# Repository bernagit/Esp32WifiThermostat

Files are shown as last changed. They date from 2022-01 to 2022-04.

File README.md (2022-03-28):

# ESP32 distribuited Thermometer

## Introduction

We made this project for an university exam, but also for improve our skill with microcontrollers, arduino and electonic in general. We started with the idea of creating a thermometer that can be viewed via telegram bot and during the implementation we decided to add some functionalities. Use of MQTT IOT protocol, photoresistor to measure brightness, use of multiple sensors, connectable from different WiFi networks, and display the information locally with a LCD.

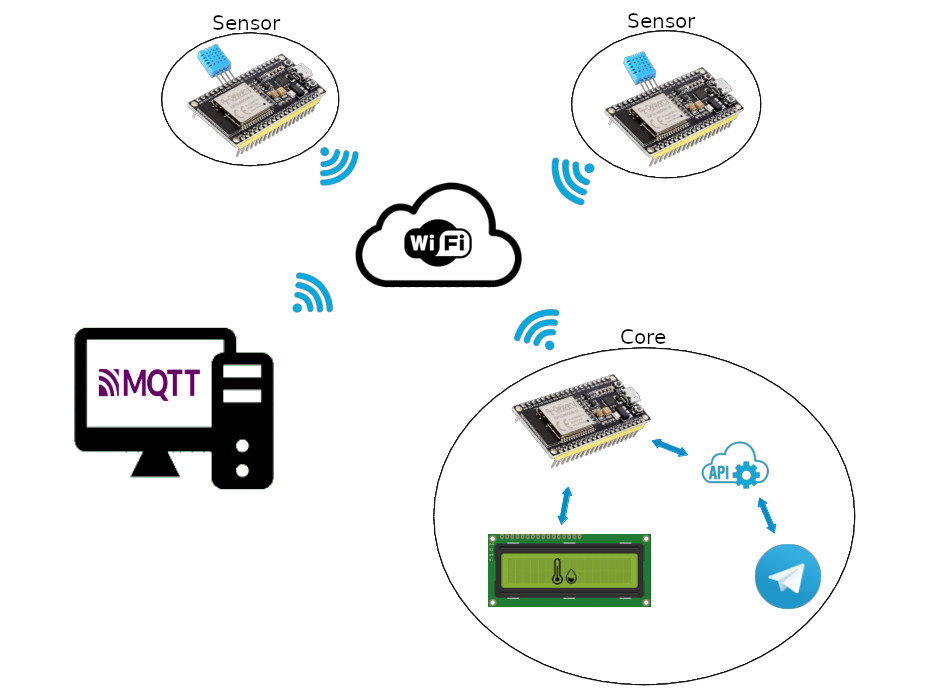
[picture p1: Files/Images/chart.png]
Project schema
- [ ] 

## How to build it

### Core of the system

##### Component List

- 1x ESP32 (with 5v output from USB)

- 1x 1602 LCD Display (not I2C version)

- 1x 10KΩ Trimmer

- 3x Button

- 3x 10KΩ Resistor

- 2x LED

##### Circuit

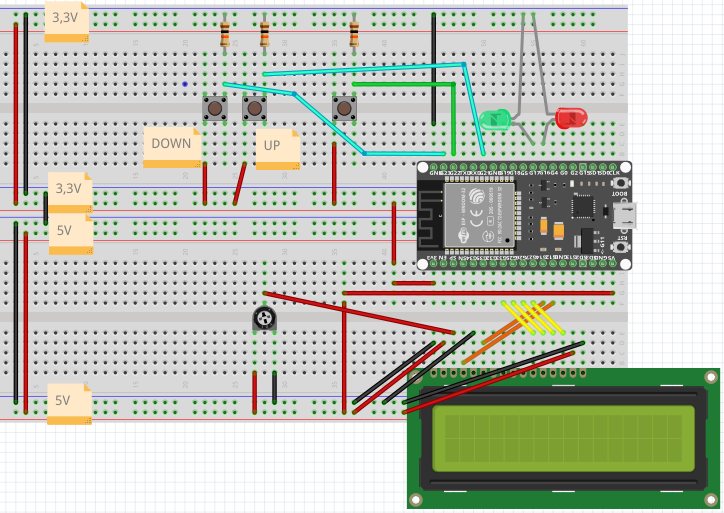
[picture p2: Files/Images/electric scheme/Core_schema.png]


### Sensor

##### Component List

- 1x ESP32 (with 5v output from USB)

- 1x 10KΩ Resistor

- 1x DHT11 Module

- 1x Photoresistor GL55

- 1x LED (or relay)

##### Photoresistor GL55

To measure enviroment brightness we decide tu use a photoresistor, a passive component that change its resistance according to the amount of light on it.

In total darkness it varies in order of MOhm, while in normal conditions it has a resistance in order of KOhm.

To connect the sensor with the microcontroller we have to make a voltage divider with a resistor of suitable value (in our case 10kOhm).

We also have to find a correct Y(gamma) value 

##### Circuit

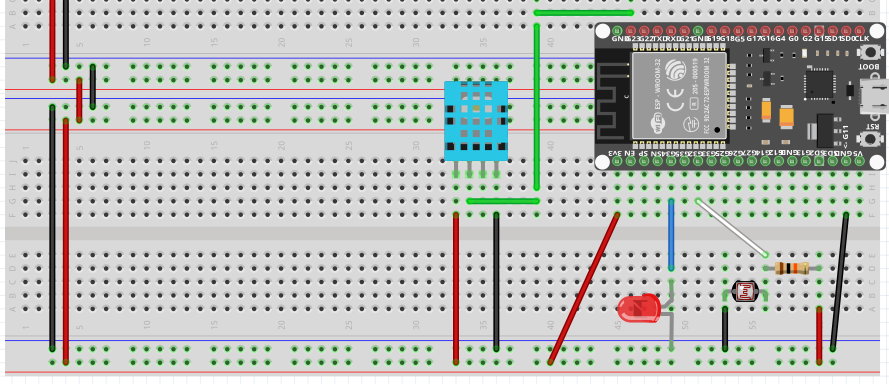
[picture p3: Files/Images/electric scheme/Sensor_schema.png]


## Communication

#### Wifi

#### MQTT

### Security Disclaimer

To make comunication between sensors and core easier we decide to use an online [MQTT Broker](https://www.mqtt-dashboard.com) that not requires credentials. Consequently the messagges from sensor are public and anyone can see them and even worse can send false data that the core will display.

In a real application sensors will publish data on a private MQTT Broker with authentication (User, Password). In this way the security of the system improves a lot.

#### Telegram

#### MultiCore

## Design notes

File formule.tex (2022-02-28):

\documentclass{article}
\usepackage[utf8]{inputenc}

\title{formule progetto elettronica}

\begin{document}
	
	\[V_0=3,3V\frac{R_p}{R_p+10K\Omega}\]	\[V_0(R_p10K\Omega)=3,3R_p\]
	\[R_p=V_0\frac{10K\Omega}{3,3V-V_0}\]
	$\log(R_p)$-$\log(10K\Omega)=\gamma^{100}_{10}[\log(lux)-\log(1)]$
	
\end{document}

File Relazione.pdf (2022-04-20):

## Progetto Arduino di Sistemi di Elettronica Digitale

## ESP32 Wifi Thermostat

Realizzato da: Bernocchi Alessandro, Ceresara Gabriele, Cherubini Mattia

Introduzione
L’obiettivo del progetto è quello di realizzare un sistema di controllo distribuito di temperatura, umidità e luminosità.
Il sistema è composto da un Core e da uno o più moduli Sensor. I Sensor sono realizzati mediante un ESP32 (sul quale è eseguito un software chiamato “Client”), un sensore di temperatura e umidità DHT11 e da un fotoresistore GL55 per la misurazione dell’intensità luminosa. Il modulo Core invece è composto da un ESP32 (sul quale è eseguito un software chiamato “Gateway”), da un display LCD non I2C e da un insieme di bottoni per la realizzazione di un’interfaccia utente locale; il Core inoltre mette a disposizione un’altro interfacciamento, realizzato mediante bot Telegram.
Il Core è in grado di rilevare nuovi sensori e aggiungerli alla lista dei sensori connessi.
Per ogni sensore collegato è possibile visualizzare temperatura, umidità e luminosità tramite telegram. Il display LCD mostra le stesse informazioni con l’aggiunta dello stato della connessione e lo stato del relè, entrambi relativi al sensore attualmente selezionato. Sono inoltre presenti 2 led di segnalazione che si attivano quando l’umidità o la temperatura rilevati da un sensore superano una certa soglia.
Dal core è possibile settare per ogni sensore la temperatura di attivazione del relè.
Le diverse entità del sistema comunicano tramite la stessa Wireless LAN oppure attraverso una diversa rete Wireless, appoggiandosi sul protocollo MQTT.

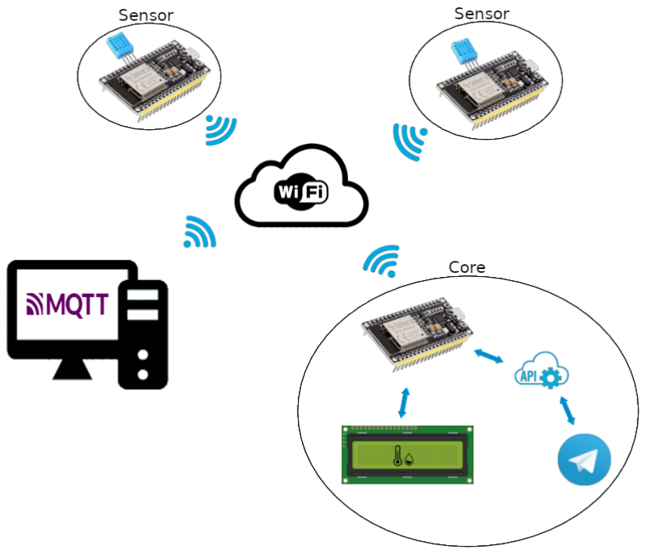
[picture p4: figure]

Comunicazione
La comunicazione avviene tra il Core e i vari Sensor in modo bidirezionale (entrambi i moduli inviano e ricevono informazioni).

I vari Sensor inviano al Core ogni 7 secondi i valori di temperatura, umidità e luminosità rilevati tramite i loro sensori.
Il Core invia ai vari Sensor i valori di temperatura impostati dall’utente tramite l’interfaccia locale, utili ad accendere o spegnere il relè usato per simulare un sistema di riscaldamento. Tale dato viene mandato ad un Sensor specifico (non viene ricevuto quindi da tutti, ma solo dal Sensor selezionato dall’utente).

How to build it

Core (sistema di controllo dei sensori)

Lista componenti
- 1x ESP32
- 1x Display 16x02 (non I2C)
- 1x Potenziometro 10kΩ
- 3x Bottone NA
- 3x Resistenza 10kΩ
- 2x Led

Realizzazione circuitale

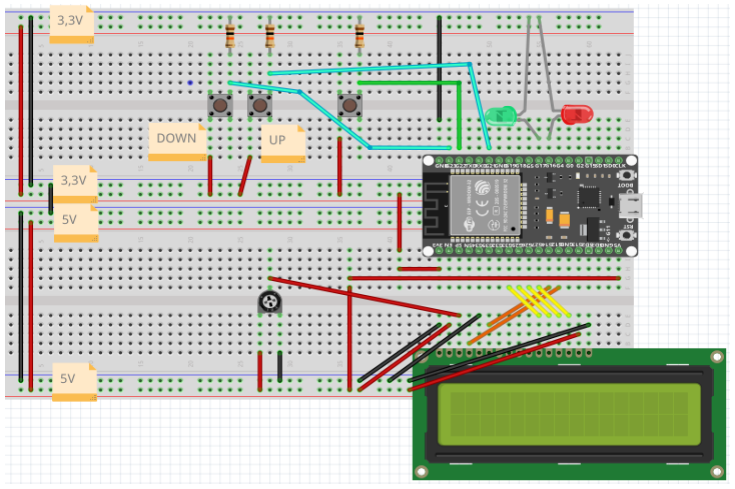
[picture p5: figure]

Sensore

Lista componenti
- 1x ESP32
- 1x Resistenza 10kΩ
- 1x Modulo DHT11
- 1x Fotoresistore GL55
- 1x Led

Fotoresistore GL55
Per la misurazione della luminosità ambientale si utilizza un fotoresistore, componente passivo che fa variare la sua resistenza inversamente alla quantità di luce presente.

In particolare, in condizioni di buio totale varia nell’ordine dei MOhm, mentre in un ambiente illuminato è nell’ordine dei KOhm .
Il sensore non può essere direttamente collegato all’ingresso del microcontrollore poiché esso è in grado di elaborare solamente dati in tensione. Va quindi inserito in un partitore di tensione con un resistore dal valore adeguato. (Nel nostro caso 10kΩ)
Non sapendo quale sensore della serie GL55 fosse a nostra disposizione è stato necessario stimare il valore di γ in modo da ricavare un coefficiente opportuno da utilizzare poi per la conversione del segnale in ingresso in Lux.
La lettura avviene tramite la funzione Arduino analogRead() la quale legge il valore del pin tramite l’attivazione di un ADC a 12 bit integrato nel microcontrollore in grado di restituirci
un valore nel range [0-4095].
Tramite il partitore di tensione si ricava la relazione che descrive la resistenza del componente che potrà essere convertita in Lux tramite le seguenti formule.

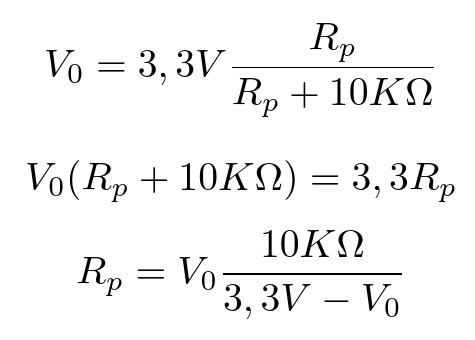
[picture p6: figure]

Realizzazione circuitale

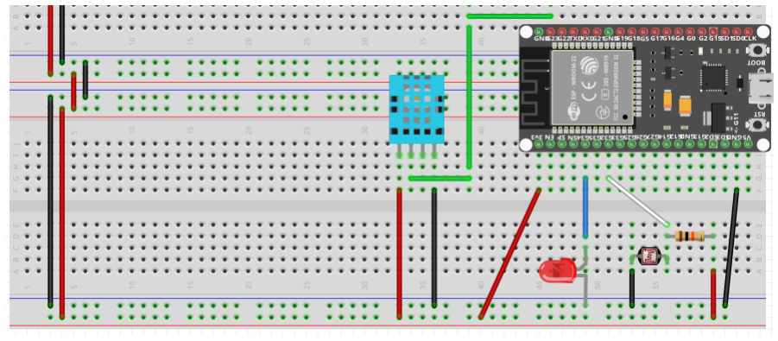
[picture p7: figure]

Communication Protocols

WIFI
La connessione al wifi è gestita tramite la libreria <Wifi.h>.
E’ necessario però definire la modalità di utilizzo tramite il metodo WiFi.mode(WIFI_STA) poiché il microcontrollore può agire anche come Access Point.

MQTT
Il protocollo di comunicazione usato dai dispositivi appartenenti al sistema è MQTT, un protocollo di rete basato sul pattern publish-subscribe, dove lo scambio di informazioni avviene tramite messaggi. Tale protocollo è ampiamente utilizzato in tutti gli ambiti nei quali esistono dei vincoli relativi alle risorse utilizzabili e dove la larghezza di banda è limitata.
MQTT definisce principalmente 2 entità: un message broker e dei client. Il broker è il server che riceve tutti i messaggi dai client e si occupa dell’inoltro delle informazioni alle destinazioni corrette, mentre i client sono un numero arbitrario di dispositivi che si collegano al broker (tramite la rete) per comunicare con il resto del sistema. Lo scambio di messaggi tra i vari client connessi al broker avviene tramite 2 azioni principali: publish e subscribe. Con l’esecuzione di una publish, un dispositivo manda informazioni; in questo caso è necessario specificare il topic sul quale eseguire l’azione e il messaggio da inviare. Sarà poi il broker ad inoltrare il messaggio a tutti i client che preventivamente avevano effettuato una subscribe nei confronti di quello specifico topic.
Nel nostro sistema l’uso del protocollo MQTT avviene tramite la libreria <PubSubClient.h>, la quale fornisce delle strutture dati e funzioni che permettono un’implementazione semplificata di tale protocollo. I metodi usati sono i seguenti:
PubSubClient client(WifiClient wifiClient) | Costruttore del client mqtt, al quale è necessario fornire il client wifi.
setServer(char* host. int port) | Imposta le informazioni relative al broker MQTT al quale ci si vuole collegare.
connect(char* name) | Si collega al broker MQTT specificato (necessario chiamare prima il metodo indicato sopra).
subscribe(char* topic) | Azione di subscribe al topic specificato come parametro
unsubscribe(char* topic) | Annulla l’azione di subscribe al topic specificato come parametro
publish(char* topic, char* msg) | Azione di publish del messaggio sul topic specificato
setCallback(function* callback) | Imposta la funzione di callback del client. Essa è chiamata ogni volta che arriva un messaggio su uno dei topic ai quali il client ha eseguito l’azione di subscribe. La funzione di callback ha come parametri un char* dove viene specificato il topic dal quale proviene il messaggio, e un char*, il quale rappresenta il messaggio vero e proprio

Nel sistema i client effettuano delle publish su topic che presentano un pattern simile: {device_id}/{data}, ovvero nella prima parte indicano il loro id (per distinguersi dagli altri dispositivi) mentre nella seconda il tipo di dato che è presente nel messaggio (nel nostro caso vengono inviate temperatura, umidità e luminosità).

Breve nota sulla sicurezza
Per semplificare la visione del progetto funzionante in università abbiamo utilizzato un MQTT Broker online (www.mqtt-dashboard.com) che non richiede credenziali. Di conseguenza:
- I messaggi inviati dai sensori sono non cifrati e visibili a tutti
- Non c’è autenticazione tra sensori e sistema centrale pertanto chiunque scriva sullo stesso Topic MQTT può introdurre dati errati che poi verranno visualizzati senza nessun controllo.
In un’applicazione reale del progetto i sensori pubblicano i loro messaggi cifrati su un Broker MQTT Privato tramite autenticazione (user e password). In questo modo si risolvono entrambi i problemi citati prima.

Telegram
La comunicazione con Telegram è gestita tramite un BOT. L’utente può inviare i comandi nella chat del BOT. Se l’utente è autorizzato gli verrà inviato un messaggio contenente una visione dei dati inviati al Core da parte dei Client MQTT al momento connessi, in caso contrario riceverà un messaggio di errore.

Lista dei comandi validi:

/start | Utente autorizzato avvia la comunicazione
/sensors | Visualizza la lista di sensori al momento connessi
/RoomN | Visualizza i dati di uno degli N sensori connessi

L’interazione è resa possibile dalle librerie <UniversalTelegramBot.h> e <ArduinoJSON.h> tramite il seguente procedimento. Quando una richiesta da parte di un utente autorizzato ha successo le informazioni relative al bot, alla chat ed allo stesso utente vengono salvate in un oggetto con il formato JSON. La comunicazione è gestita tramite un’apposita libreria che ci fornisce i seguenti metodi:

UniversalTelegramBot bot (BOTtoken, BOTclient) | Costruttore del bot con il suo token ed il client Wi-Fi
getUpdates (int msg) | Restituisce l’aggiornamento di quanti messaggi sono stati recentemente ricevuti
sendMessage (chat_id, message) | Invia un messaggio “message” sulla chat “chat_id”
bot.messages[int i] | Posizione specifica del messaggio scambiato nell’ array che li contiene
chat_id | Identificazione dell’utente
text | Contenuto testuale del comando
from_name | Contiene l’username dell’utente che invia la richiesta

MultiCore
Gli ESP-32 impiegati nel sistema sono tutti dotati di un processore dual-core, grazie al quale possono essere eseguiti più processi contemporaneamente per migliorare le prestazioni di ogni dispositivo. Questa funzionalità è utilizzabile grazie alla presenza di un sistema operativo real time (FreeRTOS) tramite il quale, con opportune API, è possibile creare dei task specificando il core sul quale devono essere eseguiti. La presenza di un RTOS permette anche di assegnare delle priorità ai vari task, che verranno gestite da quest’ultimo. La funzione usata per la generazione e l’esecuzione dei vari task è xTaskCreatePinnedToCore (documentazione delle API messe a disposizione da FreeRTOS qui). (https://docs.espressif.com/projects/esp-idf/en/latest/esp32/api-reference/system/freertos.html)
Nel nostro caso, il dual core è stato sfruttato dal sistema di controllo per gestire principalmente i task relativi alla scrittura su display LCD e alla gestione del bot Telegram, i 2 computazionalmente più “pesanti”. Ad essi è stato assegnato un core separato ed una priorità maggiore, per fare in modo che l’interazione con l’utente sia il più veloce possibile (a discapito di altri task reputati
meno importanti, come ad esempio la gestione degli interrupt generati dall’arrivo di un messaggio MQTT).

Power Save
Il sistema di controllo utilizza 2 core e sfrutta al massimo le potenzialità del processore, inoltre ha un display sempre attivo, per questo si presuppone che sia alimentato tramite apposito alimentatore.

Per quanto riguarda i sensori, si cerca invece di ridurre i consumi per un possibile utilizzo a batteria.
Si utilizza quindi la funzione esp_wifi_set_ps(WIFI_PS_MIN_MODEM) la quale rallenta la frequenza di arrivo dei messaggi Beacon con la stessa frequenza del periodo DTIM.
E’ necessario inoltre diminuire la frequenza del clock del microcontrollore con la funzione setCpuFrequencyMhz(int frequency). Nel nostro caso la frequenza del clock viene abbassata da 240MHz a 80MHz.
Risultati ottenuti:

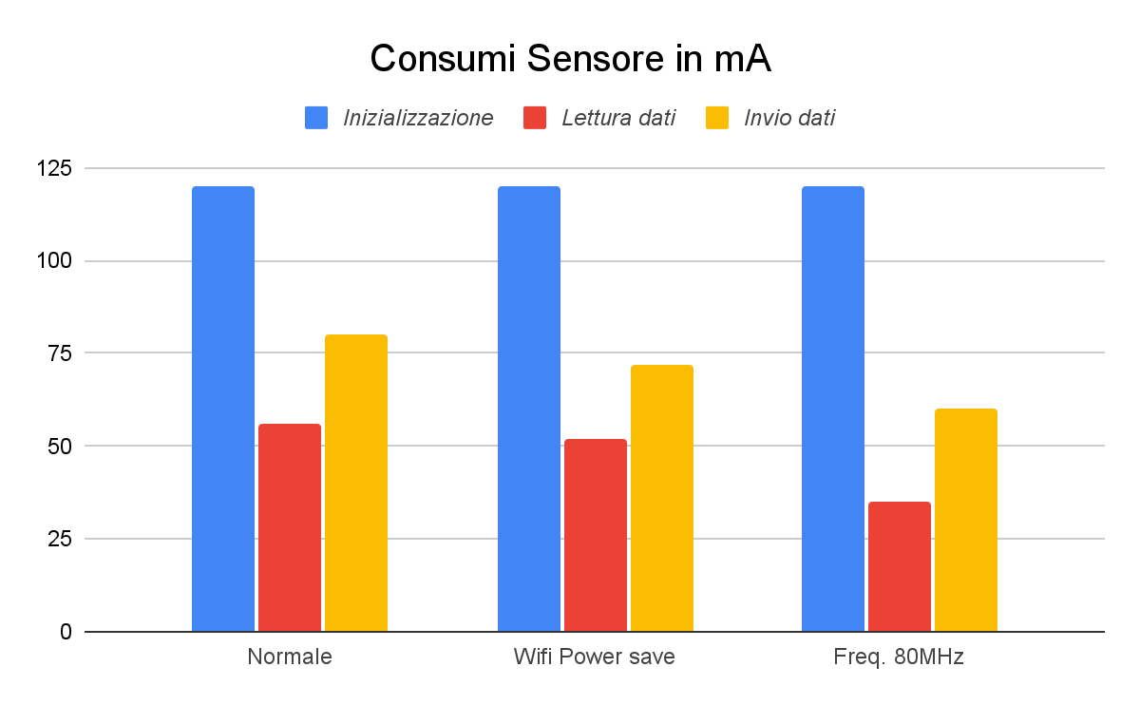
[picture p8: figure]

(documentazione API di ESPRESSIF qui) (https://docs.espressif.com/projects/esp-idf/en/latest/esp32/api-reference/index.html)

Display LCD
Per la visualizzazione “in locale” dei dati è stato usato un display 16x2 non I2C che dispone di 16 colonne e 2 righe. Indicata qui sotto una tabella con i diversi pin ed uno schema:

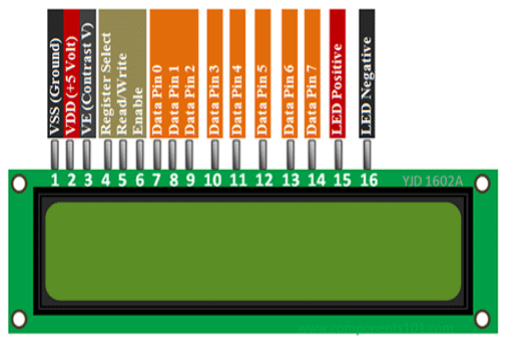
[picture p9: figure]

La programmazione avviene tramite la libreria <LiquidCrystal.h> della quale abbiamo utilizzato i seguenti metodi:

LiquidCrystal lcd(rs, enable, d4, d5, d6, d7) | Permette di creare l’oggetto inizializzando i pin connessi
lcd.begin(col, row) | Inizializzo la righe e le colonne scrivibili
lcd.setCursor(col, row) | Setto il cursore in un punto del display

lcd.print(data) | Scrive la stringa “data” dalla posizione del cursore
lcd.createChar(num, Byte data[8]) | Crea un char personalizzato assegnando un numero [0-7]
lcd.write(data) | Scrive il carattere “data” dalla posizione del cursore

Il sistema può trovarsi in uno di due stati:
- WAITING: In attesa che qualcuno si colleghi mostra l’interfaccia base, con gli slot dei dati vuoti.
- DISPLAYING: Con uno o più Sensori connessi mostra i dati ricevuti da uno di essi. Poiché il sistema è scalabile fino ad un massimo di 10 Sensori ed è possibile visualizzare sullo schermo le informazioni relative ad un solo client per volta il cambio di visualizzazione della “stanza” è gestito tramite un bottone.

Sistema di Allarmi
Il sistema di allarmi è composto da due LED sulla stazione centrale:
- LED Rosso: si accende se la Temperatura supera la soglia definita
- LED Verde: si accende se l’Umidità supera la soglia definita
Il led viene settato con la funzione digitalWrite(pin, HIGH/LOW) la quale dà un uscita digitale sul pin settato come uscita con la funzione pinMode(pin, OUTPUT), attivando il buffer Three-State posto sul GPIO selezionato.

Regolazione temperatura
Ogni sensore ha un led il quale si attiva quando la temperatura letta è inferiore ad una soglia. Tale soglia è definibile soltanto dal Core tramite appositi bottoni. Una volta settata, verrà inviata tramite MQTT al sensore.
Per semplicità il led rappresenta un relè. l’attivazione e la disattivazione corrispondono al funzionamento di un termostato.

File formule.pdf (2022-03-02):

V0 = 3, 3V

Rp
Rp + 10KΩ

V0(Rp + 10KΩ) = 3, 3Rp

Rp = V0

10KΩ
3, 3V − V0

log(Rp)-log(100KΩ) = −γ

100
10 [log(lux) − log(1)]

Luce[lux] = 10[( ⁻¹
γ

) log( Rp
100K )]

1

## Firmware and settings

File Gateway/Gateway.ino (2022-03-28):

#include <ArduinoJson.h>
#include <UniversalTelegramBot.h>
#include <WiFi.h>
#include <WiFiClient.h>
#include <WiFiClientSecure.h>
#include <LiquidCrystal.h>
#include <PubSubClient.h>
#include "Gateway.h"

/**
 * Struttura nella quale vengono salvati i dati relativi ad ogni
 * sensore connesso al sistema
 */
struct Sensor {
  String name;
  int lastConnection;
  String temperature;
  String humidity;
  String brightness;
  float setTemp;
};
//Lista dove vengono salvati tutti i sensori connessi
Sensor sensors[MAX_SENSOR_NUM];
/**
 * Indice che "scorre" sulla lista definita sopra. Questo indice punta
 * al sensore del quale si vogliono scrivere le informazioni sullo schermo
 * LCD. Ogni volta che il bottone viene premuto il suo valore è incrementato,
 * e nel caso superi il limite (arraySize, definito sotto) allora riparte da 0
 */
int selectedIndex = -1;
/**
 * Variabile che salva il numero di sensori attualmente attivi
 * Viene incrementata ogni volta che un nuovo sensore si connette
 */
int arraySize = 0;

//inizializzazione del display
LiquidCrystal lcd(14, 12, 33, 25, 26, 27);

//inizializzazione oggetti per Telegram
WiFiClientSecure clientSec;
UniversalTelegramBot bot(BOTtoken, clientSec);

unsigned long lastTimeBotRan;

//inizializzazione oggetti per MQTT
WiFiClient espClient;
PubSubClient client(espClient);

//funzione per la connessione al WIFI
void connectToWifi() {
  Serial.println("");
  Serial.print("Connecting to ");
  Serial.print(WIFI_SSID);

  WiFi.mode(WIFI_STA);
  WiFi.begin(WIFI_SSID, WIFI_PASSWORD);

  #ifdef ESP32
    clientSec.setCACert(TELEGRAM_CERTIFICATE_ROOT); // set del certificato root per api.telegram.org
  #endif
  
  while (WiFi.status() != WL_CONNECTED) {
    delay(DELAY_WIFI_TRY);
    Serial.print(".");  
  }

  Serial.println("");
  Serial.println("Wifi connected");
  Serial.println("Indirizzo IP: ");
  Serial.println(WiFi.localIP());
}
//interrupt per i tasti regolazione temperatura
int timeUpDown = 0;
bool upPressed = false;
bool downPressed = false;

void IRAM_ATTR butUpInterrupt(){
  upPressed = true;
}
void IRAM_ATTR butDownInterrupt(){
  downPressed = true;
}

//interrupt per il tasto che cambia schermata
bool buttonPressed = false;
void IRAM_ATTR buttonPressedInterrupt() {
  if(timeUpDown == 0) {
    buttonPressed = true; 
  }
}

void setTemperature(String sensorName, float temperature) {
  String topic = "progettoEle/" + sensorName + "/setT";
  client.publish(topic.c_str(), String(temperature).c_str());
}

int clearSensorList() {
  Sensor newArray[MAX_SENSOR_NUM];
  int newSize = 0;
  int now = millis();
  
  for(int i = 0; i < arraySize; i++) {
    if(now - sensors[i].lastConnection < DELETE_SENSOR_TIME * 1000) {
      newArray[newSize] = sensors[i];
      newSize++;

      //Ai sensori collegati invia la temperatura settata
      String topic = "progettoEle/" + sensors[i].name + "/setT";
      client.publish(topic.c_str(), String(sensors[i].setTemp).c_str());
    }
  }

  if(newSize == 0) {
    selectedIndex = -1;
  } else {
    selectedIndex = 0;
  }

  int difference = arraySize - newSize;
  arraySize = newSize;

  for(int i = 0; i < newSize; i++) {
    sensors[i] = newArray[i];
  }

  return difference;
}

int startMillisDrawTask = 0;
int startMillisClearSensorsList = millis();
/**
 * Funzione che gestisce la scrittura sul display LCD
 */
void DrawTaskCode(void* param) {
  for(;;) {
    delay(DELAY_WATCHDOG_RESET);
    int currentMillis = millis();
  
    if(currentMillis - startMillisDrawTask >= REFRESH_RATE){
      if(buttonPressed && selectedIndex != -1) {
        buttonPressed = false;
        selectedIndex = (selectedIndex + 1) % arraySize;
      }
    
      startMillisDrawTask = currentMillis;
      draw();
    }

    if(currentMillis - startMillisClearSensorsList >= CLEAR_SENSOR_LIST_RATE * 1000) {
      client.unsubscribe("progettoEle/#");
      
      int deleted = clearSensorList();
      if(deleted > 0) {
        lcd.clear();
        lcd.home();
        lcd.print("Deleted ");
        lcd.print(deleted);
        lcd.setCursor(0, 1);
        lcd.print("sensors");
        digitalWrite(HUMIDITY_ALARM_PIN, LOW);
        digitalWrite(TEMPERATURE_ALARM_PIN, LOW);
        delay(DELAY_AFTER_REMOVED_SENSOR);
      }

      client.subscribe("progettoEle/#");
      startMillisClearSensorsList = currentMillis;
    }
  }
}
TaskHandle_t DrawTask;

void callback(char* topic, byte* message, unsigned int length) {
  Serial.print("Message arrived on topic: ");
  Serial.print(topic);
  Serial.print(". Message: ");
  String messageTemp;
  
  for (int i = 0; i < length; i++) {
    Serial.print((char)message[i]);
    messageTemp += (char)message[i];
  }

  int firstIndex = String(topic).indexOf('/');
  String rightTopic = String(topic).substring(firstIndex + 1);
  int secondIndex = rightTopic.indexOf('/');
  String espId = rightTopic.substring(0, secondIndex);
  String param = String(rightTopic).substring(secondIndex + 1);

  Sensor s = {"", 0, "----", "--", "--", 15.0};
  Sensor *sensor = &s;
  for(int i = 0; i < arraySize; i++) {
    if(sensors[i].name == espId) {
      sensor = &sensors[i];
    }
  }

  if(sensor->name == "" && arraySize < MAX_SENSOR_NUM) {
    sensor->name = espId;
    sensors[arraySize] = *sensor;
    arraySize++;

    if(arraySize == 1) {
       selectedIndex = 0;
    }

    setTemperature(espId, 15.0);
  }

  sensor->lastConnection = millis();
  if(param == "temperature") {
    //tronco il valore di temperatura a 3 caratteri per la visualizzazione su display
    messageTemp.remove(4);
    sensor->temperature = messageTemp;
  }
  if(param == "humidity") {
    sensor->humidity = messageTemp;
  }
  if(param == "brightness") {
    sensor->brightness = messageTemp;
  }
}

void draw() {
  lcd.setCursor(0, 0);
  if(selectedIndex == -1) {
    lcd.print("Waiting for     ");
    lcd.setCursor(0, 1);
    lcd.print("connections     ");
    return;  
  }
  Serial.println(selectedIndex);
  Sensor sensor = sensors[selectedIndex];
  if(sensor.temperature.toFloat() >= WARNING_TEMP) {
    digitalWrite(TEMPERATURE_ALARM_PIN, HIGH);
  } else {
    digitalWrite(TEMPERATURE_ALARM_PIN, LOW);
  }

  if(sensor.humidity.toFloat() >= WARNING_HUM) {
    digitalWrite(HUMIDITY_ALARM_PIN, HIGH);
  } else {
    digitalWrite(HUMIDITY_ALARM_PIN, LOW);
  }
  
  lcd.print(sensor.name);
  lcd.print(" ");
  lcd.write(1);
  lcd.print(" " + sensor.temperature);
  lcd.print((char)223);
  lcd.print("C");

  lcd.setCursor(0, 1);
  lcd.write(2);
  lcd.print(" " + sensor.humidity + "%  ");

  lcd.setCursor(6, 1);
  lcd.write(3);
  lcd.print(" " + sensor.brightness + " lux ");

  
  lcd.setCursor(15, 0);
  if(sensor.temperature.toFloat() < sensor.setTemp ){
    lcd.write(5);
  }
  /**
   * Se il sensore non si connette da più di 30 secondi, viene segnalato tramite
   * un'icona nell'angolo in alto a destra del display
   * Nel ramo else viene scritto uno spazio bianco per "pulire" nel caso l'icona
   * vada eliminata
   */
  else if(millis() - sensor.lastConnection > DELAY_SENSOR_WARNING * 1000) {
    lcd.write(4);
  } else {
    lcd.print(" ");
  }
}
//funzione per la connessione al server MQTT
void connectToMQTTServer() {
  //Cicla fino a che non si connette
  while (!client.connected()) {
    Serial.print("Attempting MQTT connection...");
    //Prova a connettersi
    if (client.connect("ESP_GATEWAY")) {
      Serial.println("connected");
      //Se la connessiona va a buon fine, si fa la subscribe al topic
      client.subscribe("progettoEle/#");
    } else {
      //Se la connessione non va a buon fine, si scrivono le informazioni di errore e si riprova dopo 1 secondo
      Serial.print("failed, rc=");
      Serial.print(client.state());
      Serial.println(" try again in 5 seconds");

      delay(DELAY_AFTER_SETUP);
    }
  }
}

/**
 * Funzione che gestisce il bot telegram
 */
void TelegramBotTaskCode(void* param) {
  for(;;) {
    delay(DELAY_WATCHDOG_RESET);
    if (millis() > lastTimeBotRan + BOT_DELAY_REFRESH)  {
      int numNewMessages = bot.getUpdates(bot.last_message_received + 1);
      while(numNewMessages) {
        Serial.println("got response");
        handleNewMessages(numNewMessages);
        numNewMessages = bot.getUpdates(bot.last_message_received + 1);
      }
      lastTimeBotRan = millis();
    }
  }
}
TaskHandle_t TelegramBotTask;
//funzione che si occupa della ricezione dei messaggi e della risposta
void handleNewMessages(int numNewMessages) {
  Serial.println("handleNewMessages");
  Serial.println(String(numNewMessages));

  for (int i=0; i<numNewMessages; i++) {
    // Chat id of the requester
    String chat_id = String(bot.messages[i].chat_id);
    if(String(CHATS_ID).indexOf(chat_id) == -1){
      bot.sendMessage(chat_id, "Unauthorized user " + chat_id, "");
      continue;
    }
    
    // Print the received message
    String text = bot.messages[i].text;
    Serial.println(text);

    String from_name = bot.messages[i].from_name;

    if (text == "/start") {
      String welcome = "Welcome, " + from_name + ".\n";
      welcome += "Use the following command to know the connected sensor.\n\n";
      welcome += "/sensors\n";
      bot.sendMessage(chat_id, welcome, "");

      continue;
    }

    if(text == "/sensors") {
      if(arraySize == 0) {
        bot.sendMessage(chat_id, "No sensor is connected. Try later", "");
        continue;
      }

      String devicesList = "Sensors connected:\n";
      for(int i = 0; i < arraySize; i++) {
        devicesList += "/" + sensors[i].name + "\n";
      }

      bot.sendMessage(chat_id, devicesList, "");
      continue;
    }

    String sensorName = text.substring(1);
    Sensor sensor = {"", 0, "", "", ""};
    for(int i = 0; i < arraySize; i++) {
        if(sensors[i].name == sensorName) {
          sensor = sensors[i];
          break;
        }
    }

    String sensorInfo;
    if(sensor.name == "") {
      sensorInfo = "Sensor with name " + sensorName + " not found";
    } else {
      sensorInfo = "Data of " + sensorName + "\n";
      sensorInfo += "Temperature: " + sensor.temperature + "°C\n";
      sensorInfo += "Humidity: " + sensor.humidity + "%\n";
      sensorInfo += "Brightness: " + sensor.brightness + "lux\n";
    }

    bot.sendMessage(chat_id, sensorInfo, "");
  }
}

void setup() {
  Serial.begin(115200);

  //Pin degli allarmi settati come output
  pinMode(TEMPERATURE_ALARM_PIN, OUTPUT);
  pinMode(HUMIDITY_ALARM_PIN, OUTPUT);

  //Per sicurezza li setto subito a low, se dovranno essere high verrano impostati nella funzione draw
  digitalWrite(TEMPERATURE_ALARM_PIN, LOW);
  digitalWrite(HUMIDITY_ALARM_PIN, LOW);
  
  //pin del bottone come input
  pinMode(BUTTON_PIN, INPUT_PULLUP);
  attachInterrupt(BUTTON_PIN, buttonPressedInterrupt, FALLING);

  //setup pin regolazione temperatura
  pinMode(PINUP, INPUT_PULLUP);
  pinMode(PINDOWN, INPUT_PULLUP);
  attachInterrupt(PINUP, butUpInterrupt, FALLING);
  attachInterrupt(PINDOWN, butDownInterrupt, FALLING);
  
  // Setto il numero di righe e di colonne del display
  lcd.begin(16, 2);
  //Messaggio iniziale
  lcd.print("Welcome...");
  lcd.setCursor(0, 1);
  lcd.print("WIFI Thermostat");
  //creo i caratteri speciali per LCD
  lcd.createChar(1, termometro);
  lcd.createChar(2, goccia);
  lcd.createChar(3, lampadina);
  lcd.createChar(4, warning);
  lcd.createChar(5, fuego);
  //Connessione al wifi
  connectToWifi();
  delay(DELAY_AFTER_SETUP);

  //connessione a MQTT
  client.setServer(MQTT_HOST, MQTT_PORT);
  client.setCallback(callback);

  draw();

  //Istanziamento del task relativo alla gestione della scrittura sul display sul primo core del processore
  xTaskCreatePinnedToCore(DrawTaskCode, "DrawTask", 10000, NULL, 1, &DrawTask, 0);
  //Istanziamento del task relativo alla gestione del bot telegram sul secondo core del processore
  xTaskCreatePinnedToCore(TelegramBotTaskCode, "TelegramBotTask", 10000, NULL, 1, &TelegramBotTask, 1);
}

void loop() {
  if (!client.connected()) {
    connectToMQTTServer();
  }
  client.loop();
  //invio il messaggio sulla temperatura settata localmente
  if(timeUpDown != 0 && millis() - timeUpDown >= TIMEVISIBLE){
    setTemperature(sensors[selectedIndex].name, sensors[selectedIndex].setTemp);
    timeUpDown = 0;
    vTaskResume(DrawTask);
  }
  //gestione temperatura del riscaldamento tramite i 2 tasti
  if(upPressed){
    if(selectedIndex == -1)
      return;
    timeUpDown = millis();
    if(eTaskGetState(DrawTask) != eSuspended){
      vTaskSuspend(DrawTask);
    }
    sensors[selectedIndex].setTemp += 0.5;
    lcd.clear();
    lcd.print("Imposto temp a:");
    lcd.setCursor(1, 1);
    lcd.print(sensors[selectedIndex].setTemp);
    lcd.print((char)223);
    lcd.print("C");
    upPressed = false;
  }
  if(downPressed){
    if(selectedIndex == -1)
      return;
    timeUpDown = millis();
    if(eTaskGetState(DrawTask) != eSuspended){
      vTaskSuspend(DrawTask);
    }
    sensors[selectedIndex].setTemp -= 0.5;
    lcd.clear();
    lcd.print("Imposto temp a:");
    lcd.setCursor(1, 1);
    lcd.print(sensors[selectedIndex].setTemp);
    lcd.print((char)223);
    lcd.print("C");
    
    downPressed = false;
  }
}

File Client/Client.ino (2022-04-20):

#include <WiFi.h>
#include <WiFiClient.h>
#include <PubSubClient.h>
#include <DHT.h>
#include "Client.h"
#include "esp_wifi.h"

DHT dht(DHTPIN, DHTTYPE);

int analogInput = 0;
int vRefInput = 0;
float Volt_FOTO;
float Volt_VREF;
float Resistenza;
float temp;
int luce;

float setTemp = 0;

WiFiClient espClient;
PubSubClient client(espClient);

void connect_WiFi() {

  Serial.println();
  Serial.print("Connecting to ");
  Serial.println(WIFI_SSID);

  WiFi.begin(WIFI_SSID, WIFI_PASSWORD);
  while(WiFi.status() != WL_CONNECTED) {
    delay(DELAY_WIFI_TRY);
    Serial.print(".");
  }

  Serial.println("");
  Serial.println("WiFi connected");
  Serial.println("IP address: ");
  Serial.println(WiFi.localIP());  
  
}


void callback(char* topic, byte* payload, unsigned int length) {
  Serial.print("Message arrived [");
  Serial.print(topic);
  Serial.print("]");

  char message[length];

  for(int i = 0; i < length; i++) {
    message[i] = (char)payload[i];
  }

  Serial.print(message);

  setTemp = String(message).toFloat();
}

bool mqtt_connect() {
  while(!client.connected()) {
    Serial.print("Attempting MQTT connection...");

    String clientID = "esp1-";
    clientID += String(random(0xffff), HEX);

    if(client.connect(clientID.c_str())) {
      Serial.println("Connected to MQTT broker!");
      
    } else {
      Serial.print("failed, rc=");
        Serial.print(client.state());
        Serial.println(" try again in 5 seconds");
        delay(DELAY_AFTER_SETUP);
    }
  }
}

void setWiFiPowerSavingMode(){
    //funzione che rallenta la frequenza di arrivo dei messaggi Beacon dall'access point a cui è collegato
    //Minimum modem power saving. In this mode, station wakes up to receive beacon every DTIM period (DOCUM UFF ESPRESSIF)
    esp_wifi_set_ps(WIFI_PS_MIN_MODEM);
}

void setCpuFrequency(int freq){
  setCpuFrequencyMhz(freq);
 
  Serial.print("CPU Freq: ");
  Serial.println(getCpuFrequencyMhz());
}

int volt_to_lux(int v) {
  Volt_FOTO = float(v) * (VREF / float(4095));
  Serial.print(" ADC = ");
  Serial.print(v);
  Serial.print(" V_FOTO [mV] = ");
  Serial.print(Volt_FOTO);

  Resistenza = R * Volt_FOTO / (VREF - Volt_FOTO);
  if (Resistenza >= 999999.0) {
    Resistenza = 999999.0; 
  }

  Serial.print(" Resistenza[Ohm]=");
  Serial.print(Resistenza);
 
  temp = log10(Resistenza/100000.0);
  temp = -(1/0.72)*temp;
  luce = (int)pow(10, temp);

  if(luce > 9999.0) {
    luce = 9999.0;
  }
  return luce;  
}

void setup() {
  Serial.begin(115200);
  
  pinMode(FOTO_PIN, INPUT);
  pinMode(LED_PIN, OUTPUT);
  
  connect_WiFi();
  client.setServer(MQTT_HOST, MQTT_PORT);
  client.setCallback(callback);

  //funzioni per il risparmio energetico
  setCpuFrequency(240);  //abbasso la velocità del clock da 240MHz a 80MHz
  setWiFiPowerSavingMode();
  
  dht.begin();
  
}

void loop() {
 
  if (!client.connected()) {
    mqtt_connect();
    client.subscribe("progettoEle/Room1/setT");
  }
  
  client.loop();
  
  int humidity = dht.readHumidity();
  float temperature = dht.readTemperature();
  analogInput = analogRead(FOTO_PIN);

  luce = volt_to_lux(analogInput);
  Serial.print(" Luce[Lux]=");
  Serial.print(luce);
  Serial.println(" ");

  if (isnan(humidity) || isnan(temperature)) {
    Serial.println(F("Lettura da DHT fallita!"));
    return;
  }else{  
    client.publish("progettoEle/Room1/temperature",String(temperature).c_str());
    client.publish("progettoEle/Room1/humidity",String(humidity).c_str());
    client.publish("progettoEle/Room1/brightness", String(luce).c_str());
  }

  if(temperature <= setTemp) {
    digitalWrite(LED_PIN, HIGH);
  } else {
    digitalWrite(LED_PIN, LOW);
  }
  
  delay(SEND_TIME);
}

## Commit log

2021-12-28 Add files via upload
    Sensori ESP1
2021-12-30 #sensoreFiorista #luce0
2021-12-30 #SensoreFiorista #luce0
2021-12-30 #SensorePescivendolo #AnteRebicFantasia
2021-12-30 il berna speck inglish
2022-01-03 il berna modifica cose
2022-01-03 al berna piace il... commit
2022-01-03 cheru smettila di cambiare gli schemi elettrici
2022-01-03 Spingi Sensore, SPINGERE
2022-01-07 power save si o no?
2022-01-08 modifiche del sabato sera
    [gateway.fzz, sensor.fzz]
